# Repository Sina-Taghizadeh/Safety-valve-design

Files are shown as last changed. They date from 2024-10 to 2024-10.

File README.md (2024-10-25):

# Safety-valve-design
We have designed a component that is placed in the fluid inlet path of a device to prevent the entry of fluid with a pressure exceeding the device's capacity.

**About the Project**

* **Course:** Machine Design 1
* **Completion Date:** Jan 2020
* **Team:** The project was completed in a group of two students.
* **Instructor:** Dr. Abdolhossein Jalali
* **Language:** Persian

t1

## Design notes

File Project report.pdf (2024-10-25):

# به نام خدا

## پروژه ي درس طراحی اجزا 1

## طراحی شیر اطمینان

## استاد درس: دکتر جلالی

## طراحان: محمد خراسانی سینا تقی زاده

بهمن 98

## تشخیص نیاز:

بسیاري از قطعات مورد استفاده در صنعت مثل لوله ها، شیرآلات، مخازن تحت فشار و... که با یک سیال کار میکنند داراي ماکزیمم فشاري میباشند که در صورت افزایش فشار بیش از آن مقدار، قطعه ي مذکور دچار مشکل خواهد شد؛ حال این مشکل میتواند مواردي همچون خلل در عملکرد درست و پیش بینی شده براي قطعه، کاهش عمر یا حتی خراب شدن آنی آن و یا مواردي از این قبیل باشد.
با این مقدمه میتوان این موضوع را دریافت که طراحی و ساخت قطعه اي براي اینکه اجازه ندهد تا این قطعات در معرض فشار بیش از فشار ماکزیمم بیان شده براي آنها قرار بگیرند؛ امري ضروري است.
لذا با توجه به ضرورت آن ما نیز در ادامه به آن میپردازیم.

## تعریف مسئله:

ما بایستی قطعه اي طراحی کنیم که در مسیر سیال ورودي به دستگاه ی که باید از آن در برابر فشار بیش از حد توان آن جلوگیري شود، قرار گیرد (با توجه به دستگاهی که از آن محافظت میشود این فشار متغیر است) و اجازه ي ورود سیال با فشار بیشتر را ندهد. در این پروژه فرض ابتدایی ما بر این است که فشار ماکزیمم دستگاهی که قرار است از آن محافظت کنیم bar5 میباشد یعنی در صورت افزایش بیشتر فشار، قطعه ي طراحی شده ي ما باید طوري عمل کند این فشار را به زیر فشار بحرانی برساند. همچنین این قطعه ي ما بایستی به گونه اي باشد که تحت فشار هاي پایین از فشار بحرانی، خللی در عملکرد دستگاه وارد نکند و فقط در مواقع لزوم وارد عمل شده و از دستگاه محافظت کند . طبیعتا قطعه ي ما بایستی یک ورودي یا انشعات از فشاري که میخواهد آن را بررسی و طبق آن عمل کند داشته باشد. همچنین براي کاهش فشار بایستی یک خروجی نیز به محلی دیگر داشته باشد.

همچنین بایستی عضو نسبتا هوشمندي داشته باشد که تشخیص دهد چه زمانی باید این کار تخلیه را انجام داده و چه زمانی متوقف شود. علاوه بر این ها این عضو باید قابلیت تنظیم براي فشار هاي مختلف را نیز داشته باشد. حال یا درون خودش این مسئله تعبیه شود یا توسط عضوي دیگر این مسئله حل شود.

## ایده ها:

براي این عضو هوشمند که در قسمت قبل بیان شد میتوان از یک سنسور الکترونیکی قابل تنظیم که به فشار بیشتر از فشار بحرانی دستگاه حساس میباشد استفاده کرد به این صورت که در فشار هاي بالاتر دریچه ي خروج را باز بکند و پس از بازگشت به فشار نرمال دریچه را ببندد. ایده ي دیگر استفاده از تعدادي وزنه میباشد که با توجه به فشار مورد نیاز ما روي قسمت ورودي سیال قرار گیرد و این وزنه ها طوري گذاشته شوند که سیال وقتی به فشار بحرانی براي دستگاه رسید بتواند وزنه ها را کنار زده و راه خود را به خروجی باز کند و پس از نرمال شدن فشار دوباره این وزنه ها خروجی را مسدود کنند. ایده ي دیگر که عملکردي مشابه ایده ي قبل دارد استفاده از فنر میباشد که رفته رفته با افزایش فشار سیال فشرده تر شده و زمانی که به فشار مورد نظر میرسد، راه خروجی را باز کند و پس از برگشت فشار به حالت نرمال، این راه را ببندد.

## تجزیه و تحلیل ایده ها با توجه به قوانین موجود:

با توجه به استفاده کردن این قطعه در محیط هایی که با سیالات سروکار داریم شاید ایده ي اول که استفاده از سنسور الکترونیکی فشار بود چندان مناسب نباشد همچنین این مورد نیاز به یک منبع انرژي خارجی نیز خواهد داشت که بایستی تامین شود و امکان خطا نیز در آن به دلیل مشکل در منبع انرژي، تماس با سیال یا موارد مشابه ریسک استفاده از آن را افزایش میدهد. علاوه بر این ها هزینه ي استفاده از این سنسور احتمالا در هزینه ي تمام شده ي محصول تغییرات زیادي ایجاد خواهد کرد شاید به صرفه نباشد.

ایده ي دوم استفاده از تعدادي وزنه بر خلاف ایده ي اول نیازي به منبع انرژي خارجی نخواهد داشت لذا از این منظر نسبت به مورد قبل بهتر است. ولی وجود تعدادي وزنه با توجه به فشار هاي بالایی که قرار است قطعه با آن کار کند حتما وزن و فضاي زیادي را اشغال خواهد کرد که اصلا مناسب نیست و به تبع آن هزینه ي بالایی نیز در پی خواهد داشت. ایده ي سوم که استفاده از فنر است همانند مورد بالا نیاز به منبع انرژي خارجی ندارد و همچنین بر خلاف مورد بالا فضا و وزن زیادي نیز اشغال نخواهد کرد و از نظر اقتصادي به صرفه تر از دو مورد قبل خواهد بود.
در رابطه با قابل تنظیم بود آن نیز میتوان با فشرده و یا آزاد کردن آگاهانه ي آن تغییراتی در نیرویی که به دریچه ي ورودي وارد میکند ایجاد نمود و تحت فشار هاي مختلف دلخواه از آن بهره برد.
این مسئله را میتوان به وسیله ي یک پیچ که به یک سر فنر وصل میباشد انجام داد به این صورت که با چرخاندن پیچ میتوان طول اولیه ي فنر را تغییر داده و با توجه به دانستن گام و پیشروي پیچ این مورد را قابل تنظیم توسط کاربر قرار داد.

## انتخاب طرح بهینه با توجه به اهداف تعریف شده:

در نهایت طرحی که مطرح میشود همان شیر اطمینان مرسوم در بازار است که داراي یک ورودي ، یک خروجی ، یک ساچمه که مسیر را مسدود کرده و آب بندي را نیز بهتر انجام دهد،یک فنر که با توجه به فشار مورد نظر طراحی شود و بالاي ساچمه قرار گیرد و در نهایت پیچ که با توجه به تنش هاي وارده به آن طراحی شده و قابلیت حرکت نیز با توجه به نیاز کاربر به فشار هاي مختلف داشته باشد.
یک شماتیک کلی از این طرح به صورت زیر در نرم افزار کتیا مدل شده است:

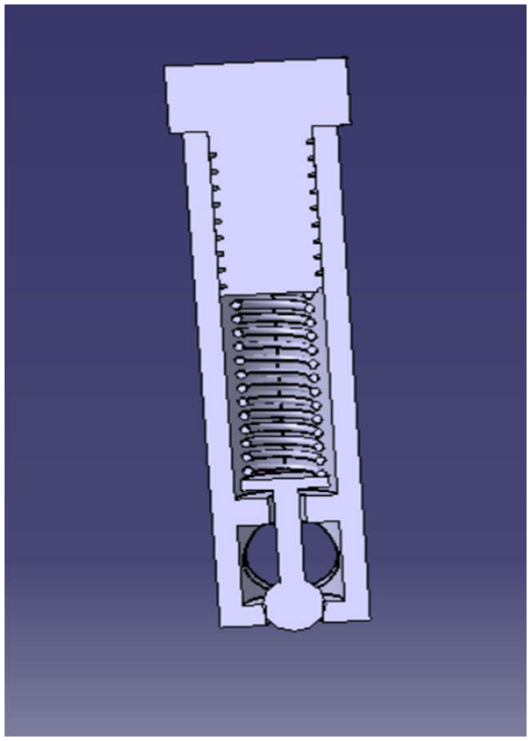
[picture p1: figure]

## طراحی فنر:

برنامه اي براي این منظور در پایتون نوشته ایم که براي bar5 = pressure set آنرا اجرا نموده ایم نتایج آن به شرح زیر شده است:

Fmin = 31.808619 N

P_reseating = 4.050000000000001 bar blow_down = 0.9499999999999997 bar

k = 3.1808619 N/mm

Fmax = 63.617238 N

P_max (full open mode) = 8.100000000000001 bar

تمام فنرهاي پیشنهادي:

{-816.6871368531117: {‘d’: 1.5000000000000002, ‘Sut’: 1650.7982657433342, ‘Ssy’: 742.8592195845005, ‘C’: 7.537810701259146, ‘D’: 11.30671605188872, ‘Fs’: 73.15982369999999, ‘Na’: 11.010594399063397, ‘Ls’: 19.515891598595097, ‘k’: 3.1808619, ‘Lo’: 42.51589159859509, ‘ys’: 22.999999999999993, ‘Locr’: 59.47332643293467, ‘nf’: 1.4999999999999996, ‘ns’: 1.1559012752870854, ‘fom’: -816.6871368531117}, -835.7441061690088: {‘d’: 1.6000000000000003, ‘Sut’: 1630.6792557350602, ‘Ssy’: 733.8056650807772, ‘C’: 8.789102671550067, ‘D’: 14.06256427448011, ‘Fs’: 73.15982369999999, ‘Na’: 7.408692251120687, ‘Ls’: 15.053907601793103, ‘k’: 3.1808619, ‘Lo’: 38.0539076017931, ‘ys’: 22.999999999999996, ‘Locr’: 73.96908808376537, ‘nf’: 1.4999999999999998, ‘ns’: 1.1418137942128275, ‘fom’: -835.7441061690088}, -872.9453620835576: {‘d’: 1.7000000000000004, ‘Sut’: 1612.0037512811089, ‘Ssy’: 725.401688076499, ‘C’: 10.11474647640894, ‘D’: 17.1950690098952, ‘Fs’: 73.15982369999999, ‘Na’: 5.11943817021121, ‘Ls’: 12.10304488935906, ‘k’: 3.1808619, ‘Lo’: 35.103044889359055, ‘ys’: 22.999999999999993, ‘Locr’: 90.44606299204875, ‘nf’: 1.5, ‘ns’: 1.1287370665090752, ‘fom’: -872.9453620835576}, -940.053836351354: {‘d’: 1.8000000000000005,

‘Sut’: 1594.5919496237675, ‘Ssy’: 717.5663773306953, ‘C’: 11.51625570620062, ‘D’: 20.729260271161124, ‘Fs’: 73.15982369999999, ‘Na’: 3.672628441246653, ‘Ls’: 10.210731194243978, ‘k’: 3.1808619, ‘Lo’: 33.21073119424398, ‘ys’: 23.0, ‘Locr’: 109.03590902630751, ‘nf’: 1.5000000000000007, ‘ns’: 1.1165451929419539, ‘fom’: -940.053836351354}}
بهترین فنر با توجه به fom فنر زیر میباشد که برنامه به ما میدهد:

Specifications of The best spring :

d': 1.5000000000000002, 'Sut': 1650.7982657433342,

'Ssy': 742.8592195845005, 'C': 7.537810701259146,

'D': 11.30671605188872, 'Fs': 73.15982369999999,

'Na': 11.010594399063397, 'Ls': 19.515891598595097,

'k': 3.1808619, 'Lo': 42.51589159859509,

'ys': 22.999999999999993, 'Locr': 59.47332643293467,

'nf': 1.4999999999999996, 'ns': 1.1559012752870854,

'fom': -816.6871368531117e-9
با توجه به آزمون و خطا هاي موجود بهتر است فنر براي فشار bar5 ابتدا توسط پیچ به اندازه ي 10 میلیمتر فشرده شود و فشردگی نهایی نیز که ناشی از بیشترین فشار قابل تحمل است 20میلیمتر در نظر گرفته میشود . اگر point set به جاي 5 بار که ما طراحی را براي آن انجام داده ایم فشار کمتري مانند 4 بار شود فقط لازم است فشردگی اولیه را تغییر داد(کمتر کرد) که براي آن نیز گزینه اي در برنامه در نظر گرفته شده است.مثلا همین فنر بالا را اگر بخواهیم براي 4بار به کار ببریم؛ فشردگی اولیه به جاي 10 میلیمتر بایستی 8 میلیمتر باشد یعنی با توجه به گام پیچ که در اینجا 2 میلیمتر میباشد ي دور باید آن را در جهت پادساعتگرد بچرخانیم .

براي اطمینان بیشتر داده هاي پیشنهادي بالا را به صورت دستی نیز چک کرده ایم.(عکس پایین)

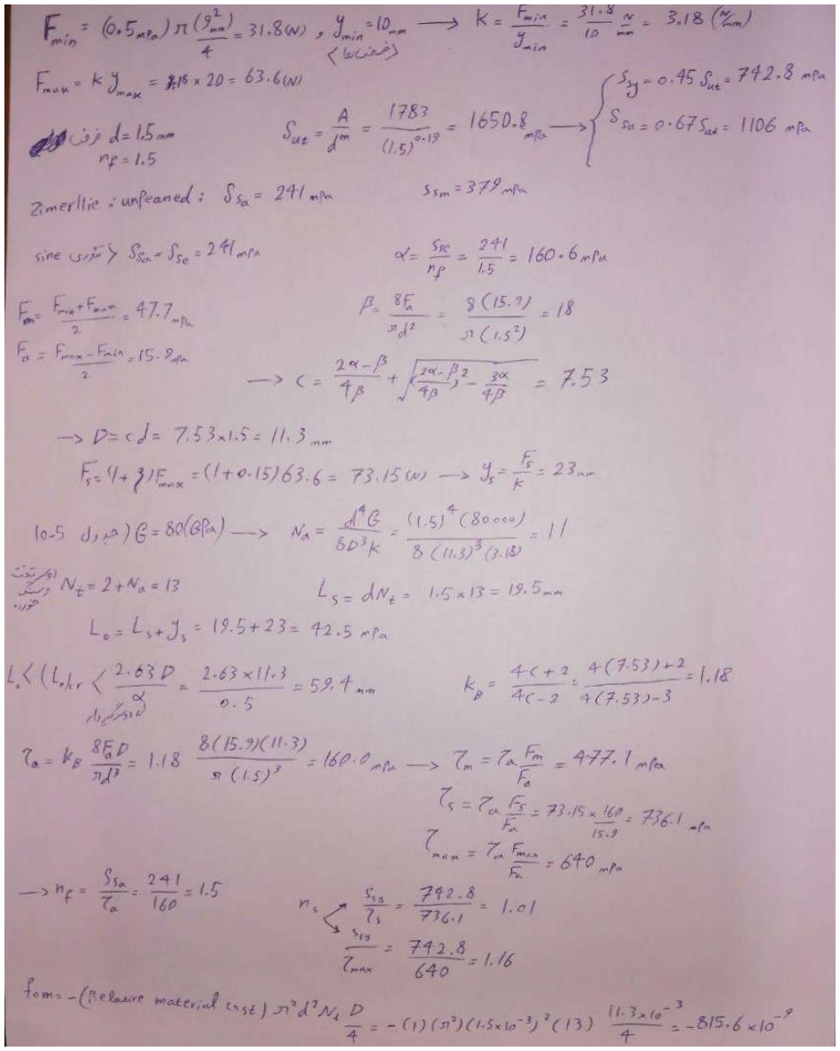
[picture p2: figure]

## طراحی پیچ:

با توجه به ابعاد فنر طراحی شده پیچ هاي 14M و 16M قابل بررسی است. با توجه به مقاومت پیچ ها و نیروهاي اعمالی به پیچ (که همان نیروهاي اعمالی به فنر است) ضرایب اطمینان بزرگی بدست می آید و طیف گستردهاي از پیچ هاي استاندارد قابل قبول خواهد بود.
لذا ما براي نمونه روي 8.8 – 16M تنش ها را بررسی کردیم و ضرایب اطمینان بسیار بزرگ شد.(عکس پایین)

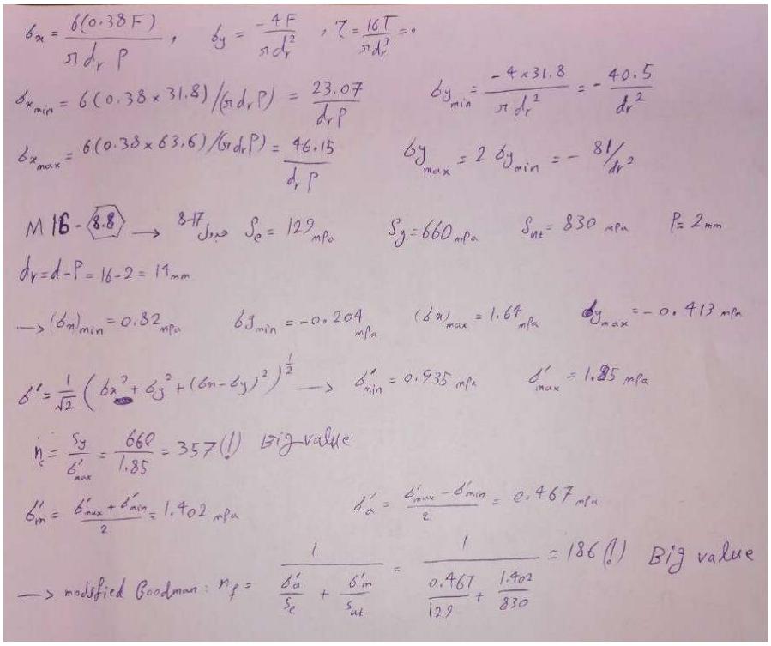
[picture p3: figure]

## طراحی بدنه:

-1طراحی ضخامت ورودي شیر که ساچمه روي آن مینشیند: در اینجا بارگذاري خستگی ناشی از نیرویی که ساچمه به ورودي وارد میکند داریم.نیروهاي وارده از 0 تا Fmin تغییر میکند.( جنس بدنه HR1006Steel علت انتخاب در قسمت دوم) ضریب اطمینان را 2 فرض کرده و ضخامت را با معیار گودمن به شکل عکس پایین محاسبه میکنیم.

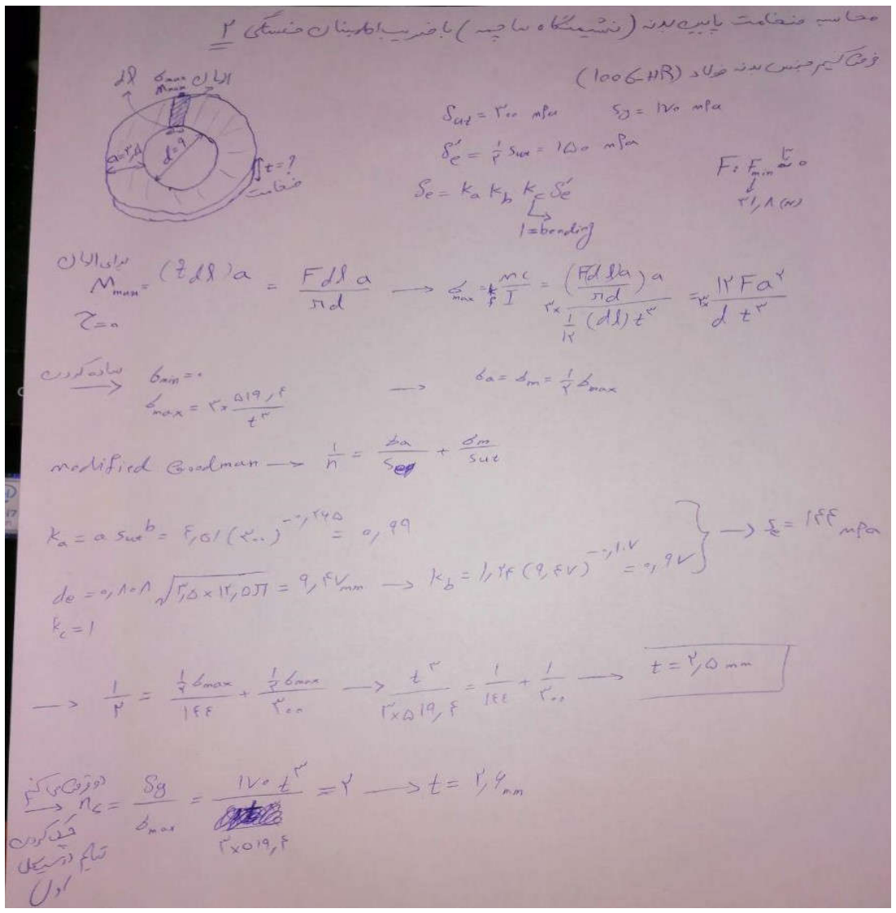
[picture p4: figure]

ضخامت نهایی ناشی از خستگی با معیار گودمن برابر 2.5 میلیمتر میشود. از نظر استاتیکی لانگر نیز بررسی را انجام میدهیم و ضخامت 2.6 میلیمتر میشود. پس در نهایت ضخامت 2.6 میلیمتر انتخاب میشود. -2طراحی قسمت رزوه شده:
فرض میکنیم جنس بدنه HR1006Steel باشد.(ضعیف ترین فولاد موجود در کتاب)چرا که اگر براي این فولاد محاسبات را انجام دهیم براي فولادهاي دیگر نیز با ضریب اطمینان بالاتر جوابگو خواهد بود.
قسمتی از بدنه که با پیچ رزوه شده است تنش هایش معادل تنش هاي روي پیچ است و رزوه ي بحرانی نیز اولین رزوه است با توجه به این که تعداد رزوه هاي پیچ که بیشتر از 7عدد میباشد اولین رزوه %38 کل بار وارده را تحمل میکند. همان محاسبات مربوط به پیچ را با متریالی که براي بدنه در نظر گرفته ایم انجام میدهیم و ضریب اطمینان با معیار گودمن برابر 126 میشود و از نظر استاتیکی 92 خواهد بود که کاملا ایمن است.

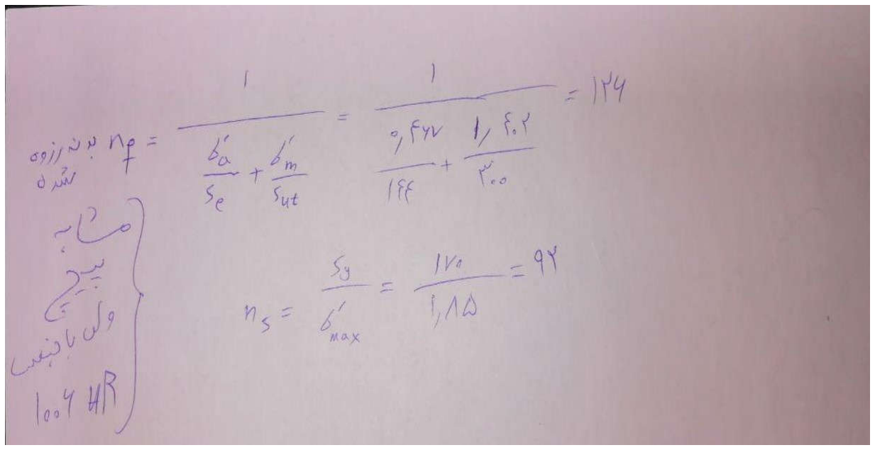
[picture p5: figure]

### نقشه ي ساخت در کتیا:

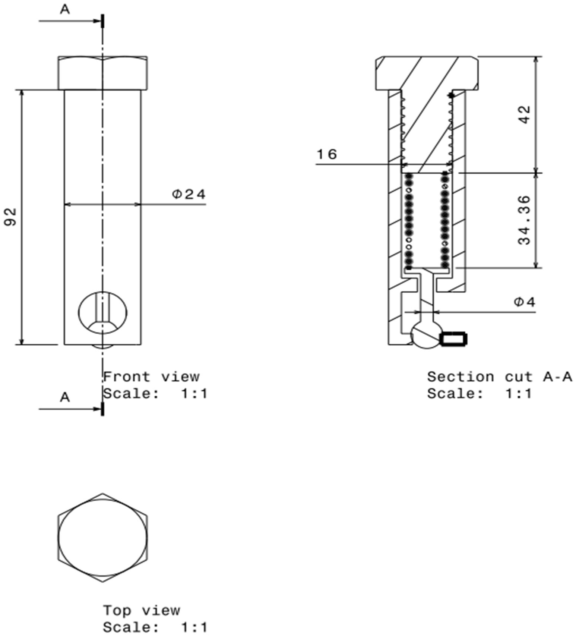
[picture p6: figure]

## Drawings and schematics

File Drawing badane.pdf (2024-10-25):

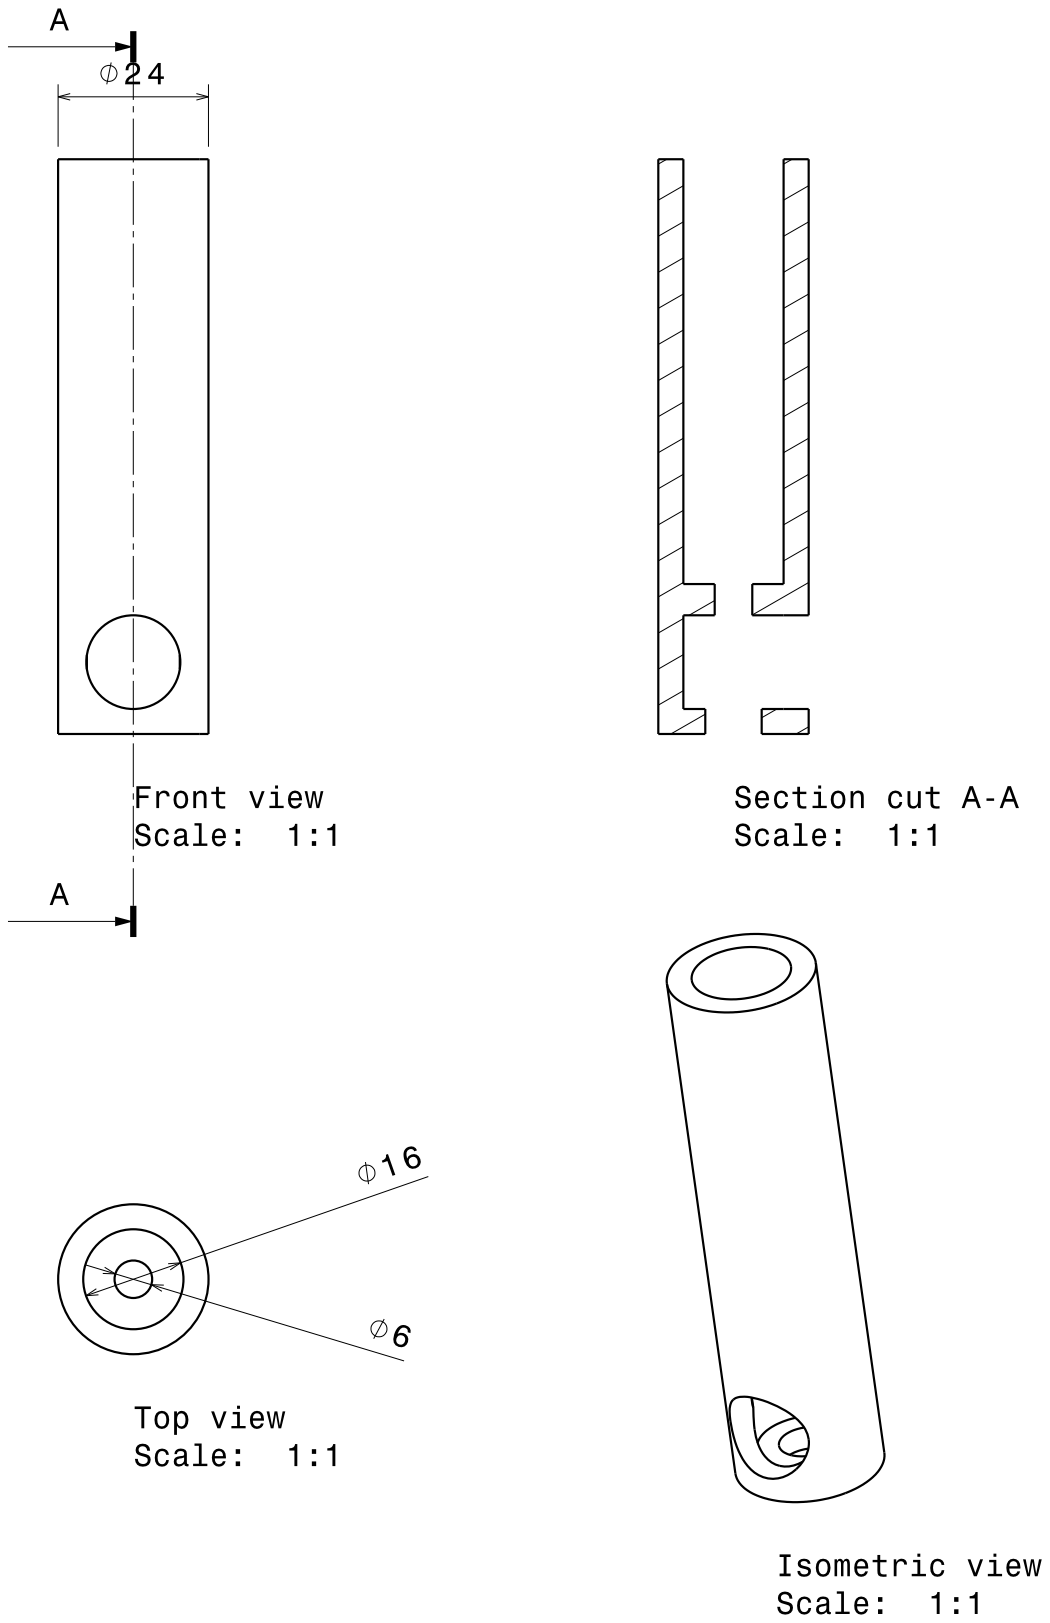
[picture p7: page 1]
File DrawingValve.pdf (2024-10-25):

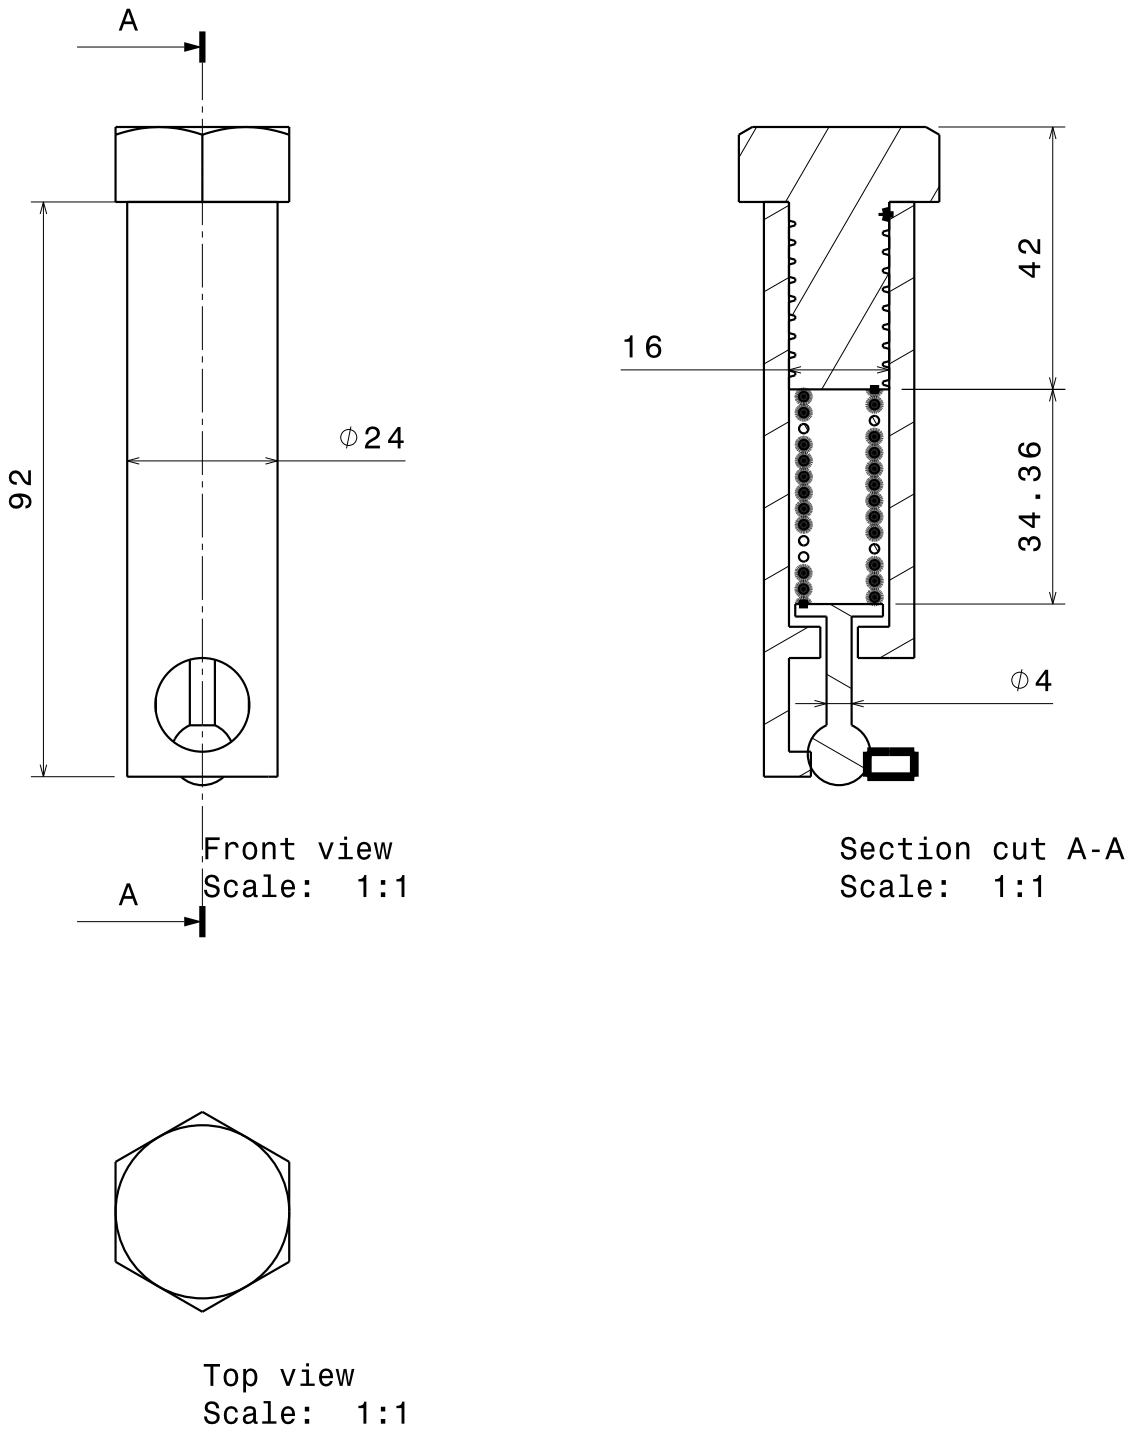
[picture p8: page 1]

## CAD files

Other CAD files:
Modeling with Catia/Valve.CATProduct
Modeling with Catia/badane asli.CATPart
Modeling with Catia/darpush.CATPart
Modeling with Catia/screw.CATPart
Modeling with Catia/spring.CATPart
